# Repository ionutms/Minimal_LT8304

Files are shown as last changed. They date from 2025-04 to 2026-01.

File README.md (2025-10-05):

# Minimal_LT8304

## Overview

This repository contains a minimal KiCad design project for the Analog Devices LT8304, a monolithic micropower isolated flyback converter. The project includes schematic designs and PCB layout files for implementing this versatile isolated power supply IC.

## Disclaimer

> [!NOTE]
> This project is provided "as is" and without any warranty, express or implied. For more details, please see the [LICENSE](LICENSE) file.

## About the LT8304

The LT8304 from Analog Devices is a monolithic micropower isolated flyback converter. It samples the isolated output voltage directly from the primary-side flyback waveform, eliminating the need for a third winding or an opto-isolator for regulation.

Key features include:

- **Input Voltage Range:** 3V to 100V.
- **Power Switch:** An internal 2A, 150V DMOS power switch is integrated.
- **Quiescent Current:** It has a low quiescent current of 116μA in sleep mode and 390μA in active mode.
- **Operation Modes:** It utilizes quasi-resonant boundary mode operation at heavy loads and low ripple Burst Mode® operation at light loads.
- **Package:** It is available in a thermally enhanced 8-lead SO package.
- **Power Delivery:** Can deliver up to 24W of isolated output power.
- **Output Voltage Setting:** The output voltage is set using two external resistors, with an option for a third resistor for temperature compensation.
- **Communication:** Uses a Serial Peripheral Interface (SPI) for configuration and data transfer.
- **Operating Temperature Range:** -40°C to +125°C.

## Project Structure

```
minimal_lt8304/
├── minimal_lt8304.kicad_sch       # Main schematic file
├── minimal_lt8304.kicad_pcb       # PCB layout file
├── minimal_lt8304.kicad_pro       # Project configuration file
├── fp-lib-table                     # Footprint library table
├── sym-lib-table                    # Symbol library table
├── project_jobs_set.kicad_jobset    # Project job settings
├── ibom.config.ini                  # Interactive BOM configuration
├── docs/                            # Documentation files
│   ├── pictures/                    # Images and photos
│   ├── schematics/                  # Schematic PDF exports
│   └── 3d_models/                   # 3D model files
└── KiCAD_Symbols_Generator/         # Submodule for symbol generation from CSV data
```

## Project Features

This design provides a minimal implementation of the LT8304 with the following features:

- **Power Supply:**
  - Wide input voltage range from 3V to 100V.
- **Channel Configuration:**
  - Isolated flyback converter configuration.
- **Bill of Materials (BOM):**
  - Interactive HTML BOM (`ibom.html`) for easy component identification and sourcing.
- **Libraries:**
  - Comprehensive symbol and footprint libraries integrated as a submodule.
- **3D Model:**
  - Includes a 3D model of the board for better visualization.

## Getting Started

### Prerequisites

- [KiCad EDA](https://www.kicad.org/) version 9.0 or later installed on your system
- Git (for cloning the repository and submodule management)

### Opening the Project

1. **Clone the repository** (including submodules):
   ```bash
   git clone --recursive https://github.com/ionutms/Minimal_LT8304.git
   ```
   
   If you've already cloned the repository without submodules, initialize them with:
   ```bash
   git submodule init
   git submodule update
   ```

2. **Open the project in KiCad**:
   - Launch KiCad
   - Click "Open Existing Project"
   - Navigate to the cloned repository folder
   - Select the `minimal_lt8304.kicad_pro` file

3. **Explore the design**:
   - Open the schematic editor to view the circuit design
   - Open the PCB editor to view the board layout
   - Review the symbol and footprint libraries used in the design

### Project Files

- **Main schematic**: `minimal_lt8304.kicad_sch` - Contains the primary circuit design with the LT8304 and support components
- **PCB layout**: `minimal_lt8304.kicad_pcb` - Physical board design file with proper component placement
- **Project configuration**: `minimal_lt8304.kicad_pro` - KiCad project settings

## Dependencies

This project has the following dependencies:

### 1. KiCAD Symbols Generator

This repository uses [KiCAD_Symbols_Generator](https://github.com/ionutms/KiCAD_Symbols_Generator) as a submodule for custom symbol generation.

To initialize the submodule after cloning this repository:

```bash
git submodule update --init --recursive
```

### 2. 3D Models

This project requires the [3D_Models_Vault](https://github.com/ionutms/3D_Models_Vault) repository for 3D models.

#### Setup for KiCAD 9:

1. Clone the 3D models repository:
   ```bash
   git clone https://github.com/ionutms/3D_Models_Vault.git
   ```

2. In KiCAD 9, add an environment variable:
   - Variable name: `KICAD9_3D_MODELS_VAULT`
   - Variable value: Full path to where you cloned the 3D_Models_Vault repository

## Usage

After setting up the dependencies, open the project in KiCad 9 to access all features including the 3D models.

## Symbol Generator Submodule

This project includes the KiCAD_Symbols_Generator as a submodule, which provides tools for generating KiCad symbols from CSV data files. For more information on using this tool, see the [KiCAD_Symbols_Generator documentation](minimal_lt8304/KiCAD_Symbols_Generator/README.md).

## Documentation

The `docs` folder contains:
- Schematic PDF exports
- Images and photos of the design
- 3D model files (GLB and WRL formats)

## Visuals

The following images showcase the PCB design from different perspectives:

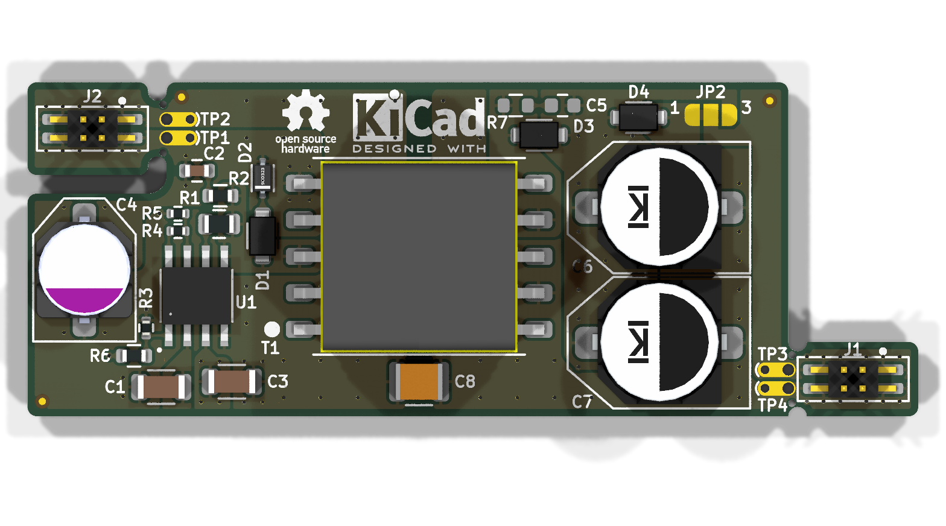
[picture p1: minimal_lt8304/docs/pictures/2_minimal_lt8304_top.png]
Top View

*Top View of the PCB*

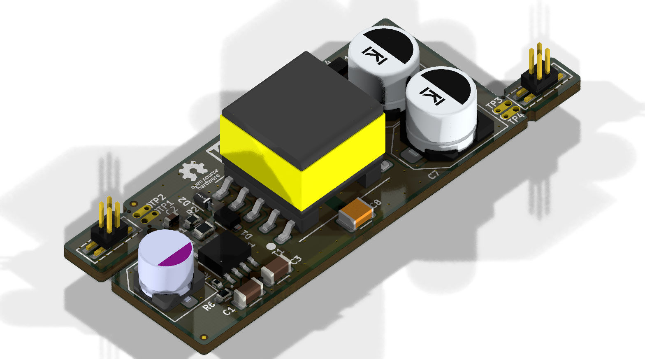
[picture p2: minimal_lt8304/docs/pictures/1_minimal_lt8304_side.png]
Side View

*Side View of the PCB*

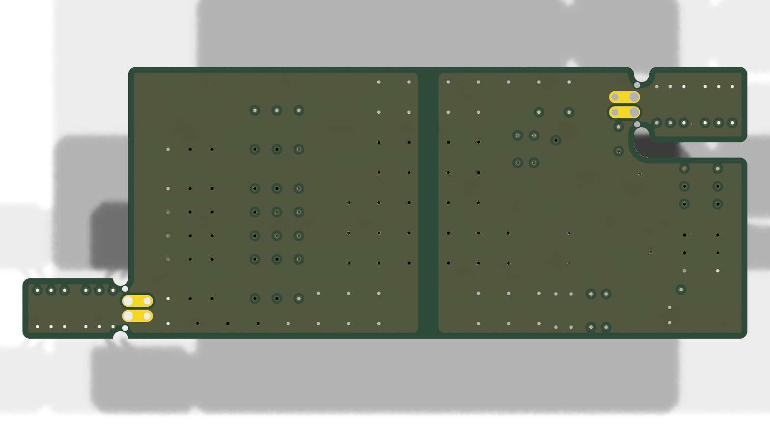
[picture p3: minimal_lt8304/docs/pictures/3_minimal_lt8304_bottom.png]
Bottom View

*Bottom View of the PCB*

## License

This project is licensed under the MIT License - see the [LICENSE](LICENSE) file for details.

## References

- [LT8304 Datasheet](https://www.analog.com/media/en/technical-documentation/data-sheets/lt8304-8304-1.pdf)
- [KiCad EDA](https://www.kicad.org/)

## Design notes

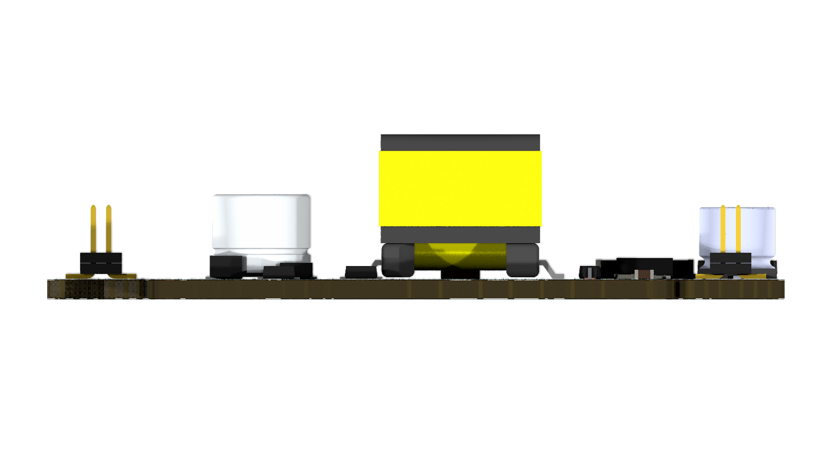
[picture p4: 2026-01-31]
minimal_lt8304/docs/pictures/7_minimal_lt8304_back.png

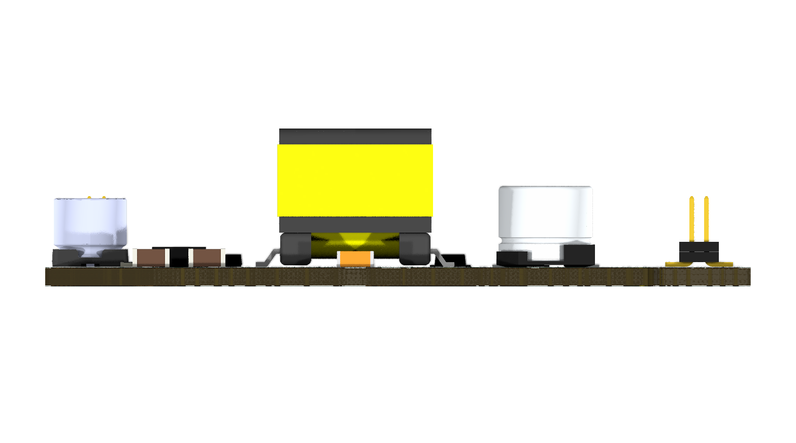
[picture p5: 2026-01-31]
minimal_lt8304/docs/pictures/6_minimal_lt8304_front.png

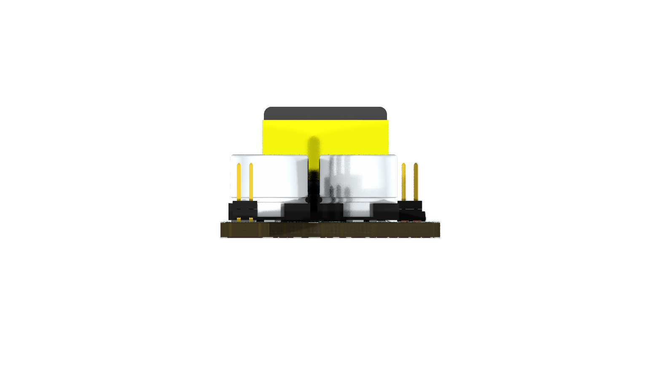
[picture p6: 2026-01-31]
minimal_lt8304/docs/pictures/5_minimal_lt8304_right.png

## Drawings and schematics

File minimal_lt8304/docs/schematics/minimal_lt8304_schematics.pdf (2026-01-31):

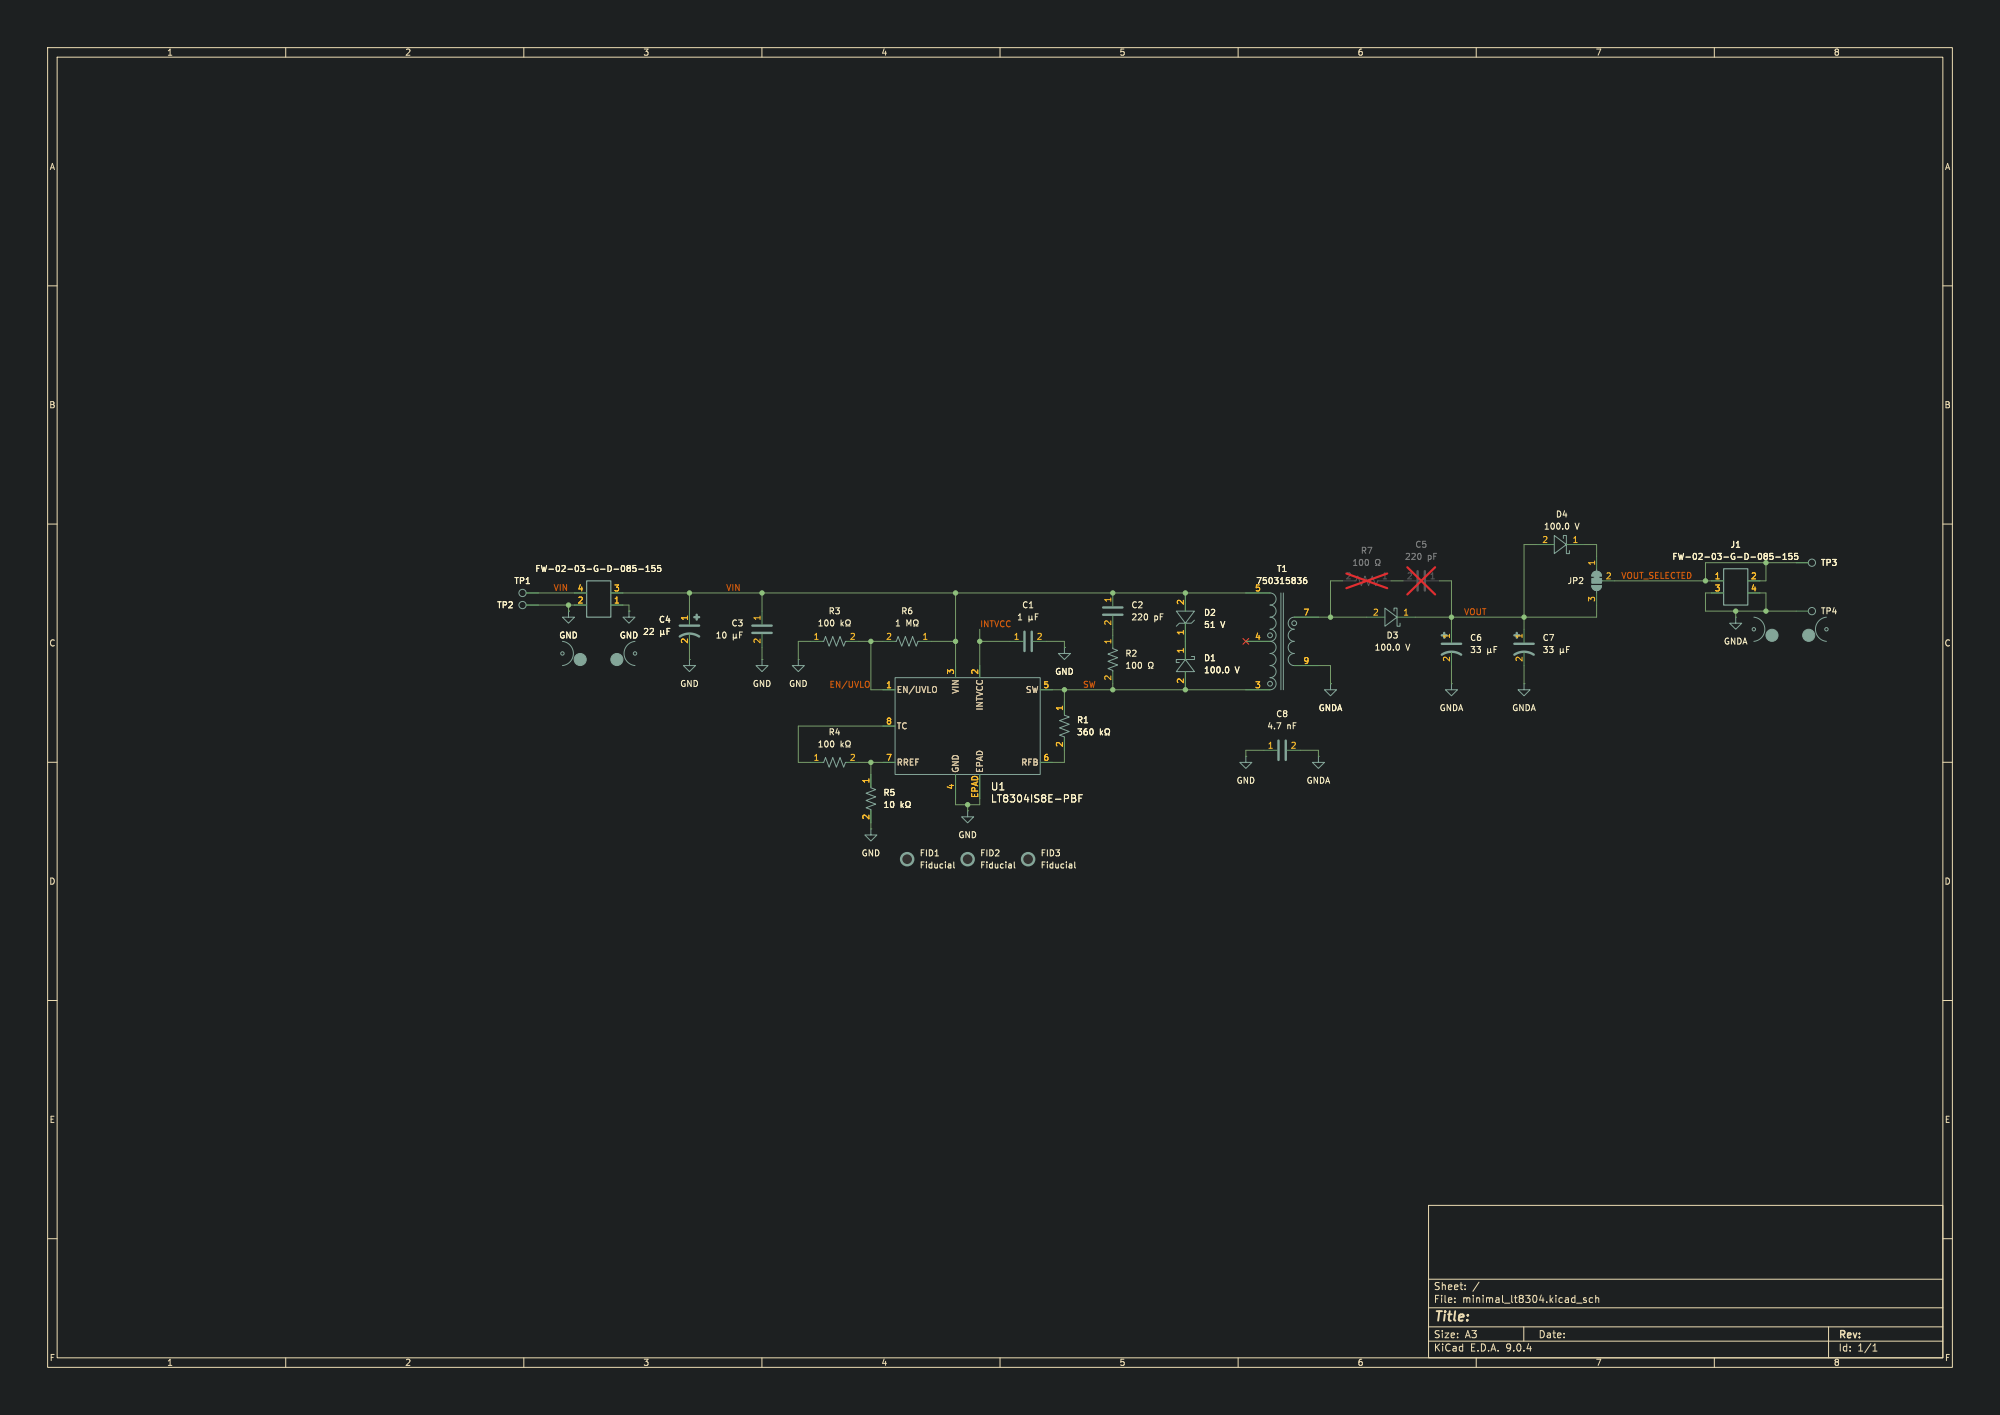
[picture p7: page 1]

33 þÿµF VOUT EN/UVLO

Id: 1/1 Title: File: minimal_lt8304.kicad_sch Sheet: /

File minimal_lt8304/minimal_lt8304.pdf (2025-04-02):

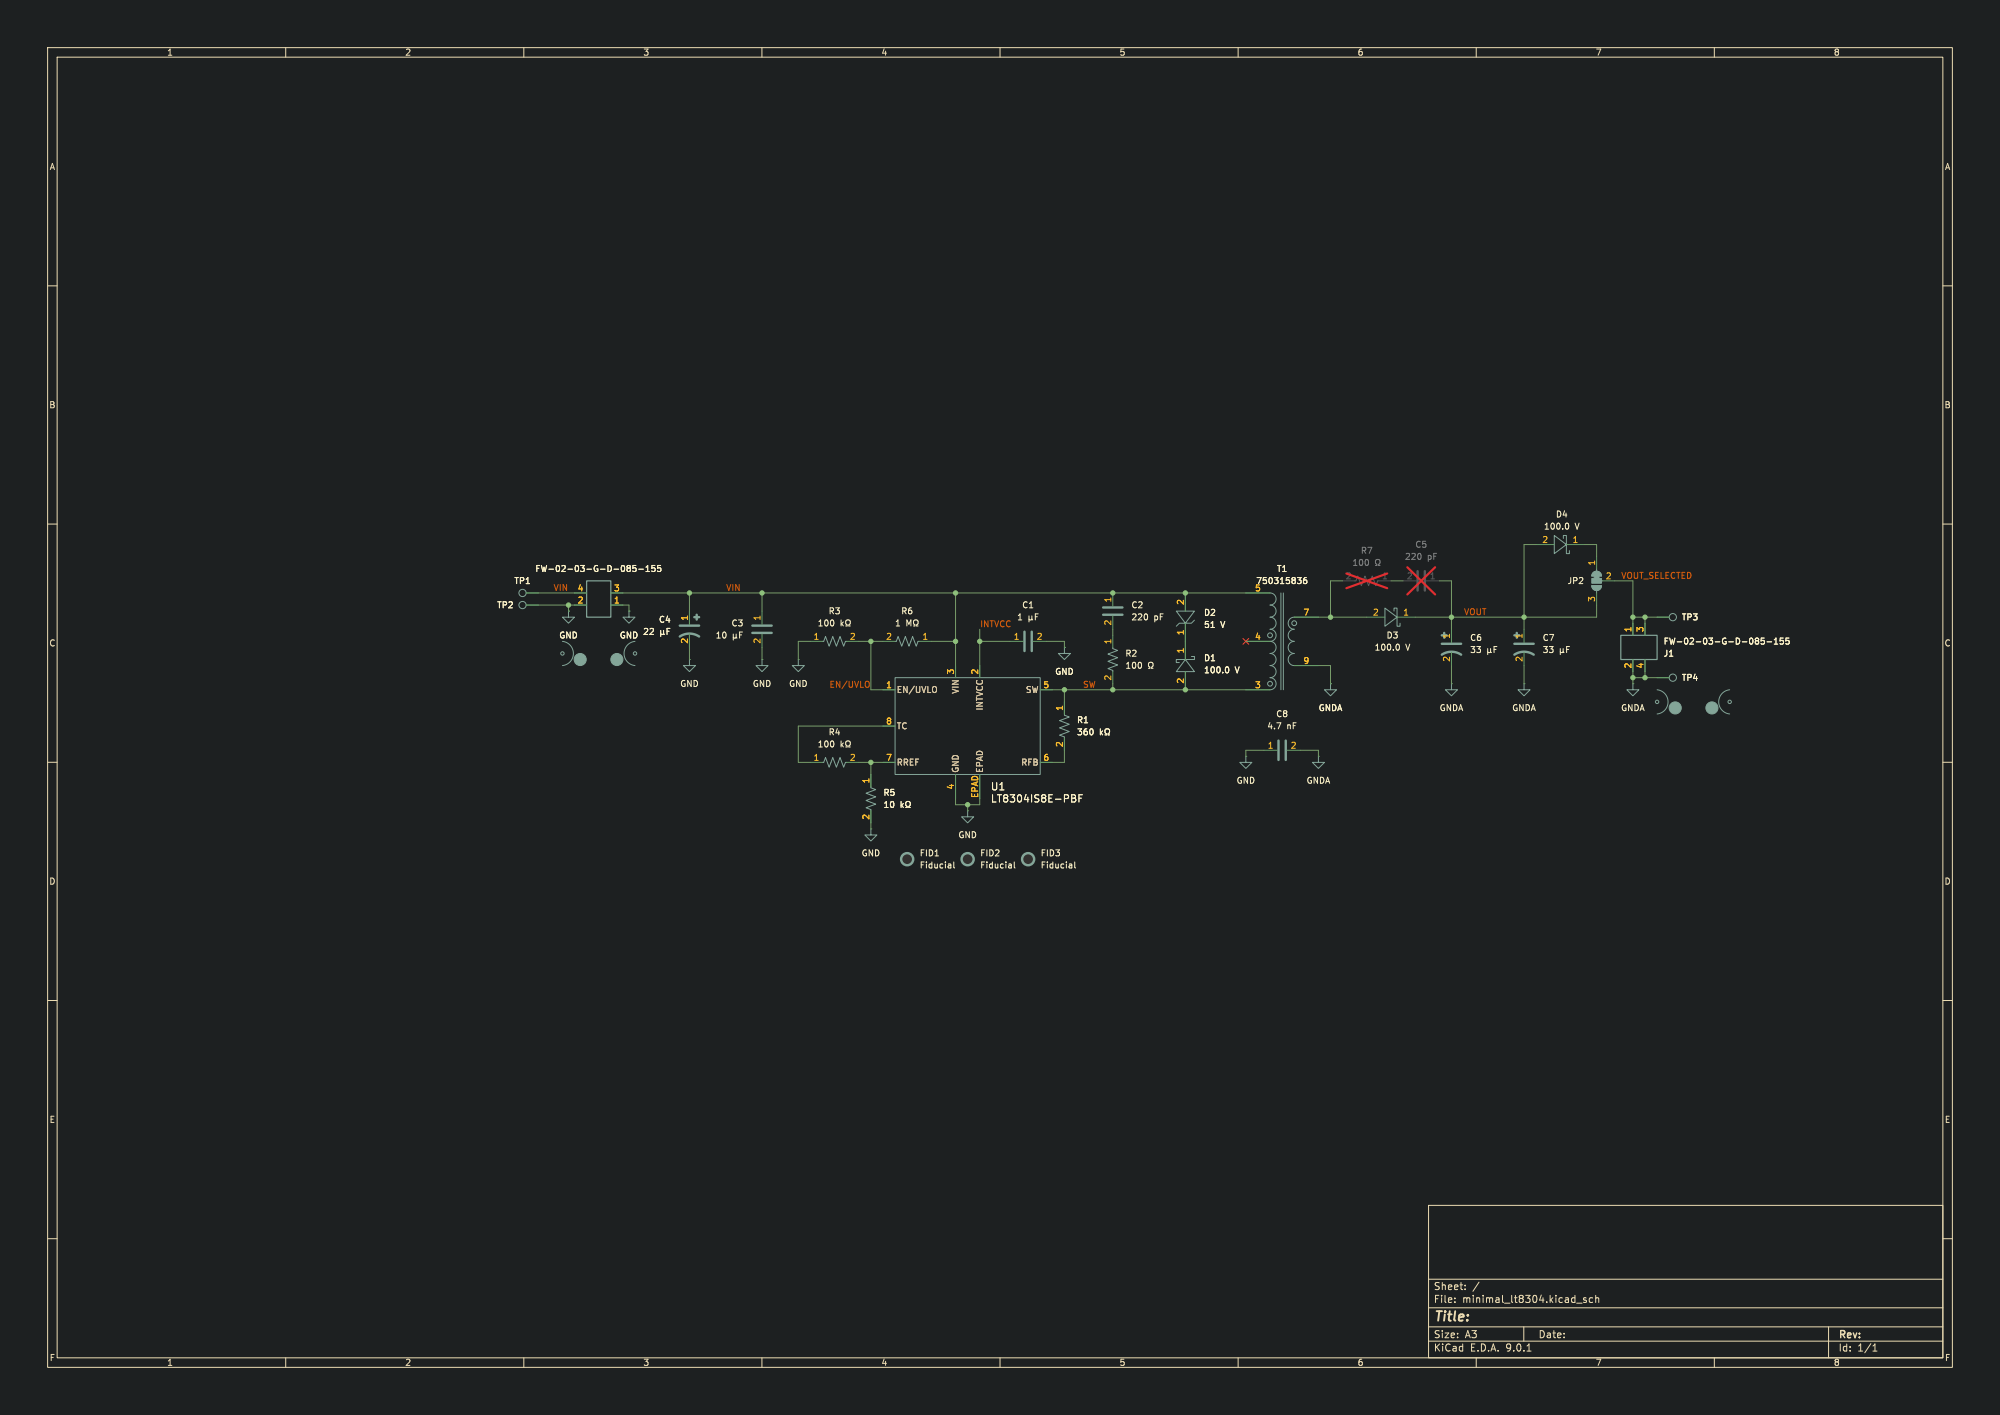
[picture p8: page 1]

Id: 1/1 Title: File: minimal_lt8304.kicad_sch Sheet: /

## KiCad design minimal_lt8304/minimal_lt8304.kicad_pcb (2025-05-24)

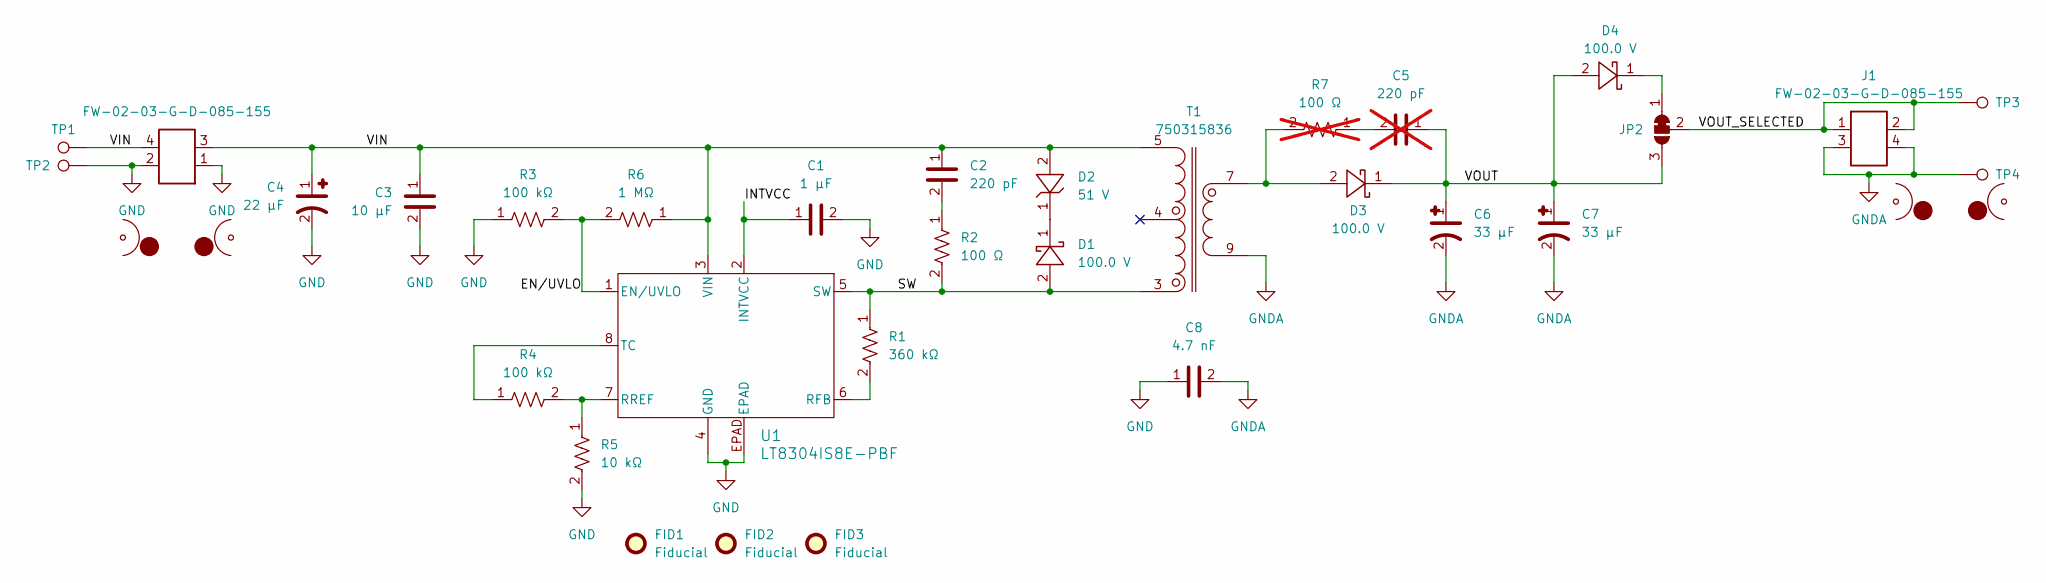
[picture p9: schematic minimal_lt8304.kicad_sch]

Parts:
C1: 1 µF; C_1206_3216Metric; Tolerance 10%; Voltage Rating 25V; MPN C1206R105K3RAC7800
C2: 220 pF; C_0603_1608Metric; Tolerance 5%; Voltage Rating 50V; MPN CC0603JRNPO9BN221
C3: 10 µF; C_1206_3216Metric; Tolerance 10%; Voltage Rating 50V; MPN CL31B106KBHNNN#
C4: 22 µF; C_023x0248_5_9x6_3Metric; Tolerance 20%; Voltage Rating 50V; MPN 50SVPK22M22
C5: 220 pF; C_0603_1608Metric; Tolerance 5%; Voltage Rating 50V; MPN CC0603JRNPO9BN221; not fitted
C6, C7: 33 µF; C_034x0263_8_0x6_7Metric; Tolerance 20%; Voltage Rating 50V; MPN A768KE336M1HLAE042336
C8: 4.7 nF; C_1210_140_3225Metric; Tolerance 10%; Voltage Rating 1.5kV; MPN C1210C472KFRACAUTO
D1, D3, D4: 100.0 V; SOD123W; MPN PMEG10020AELR
D2: 51 V; SOD323; MPN BZX384-B51
FID1, FID2, FID3: Fiducial; Fiducial_0.5mm_Mask1mm
J1, J2: FW-02-03-G-D-085-155; Current Rating (A) 5.2; Voltage Rating (V) 300; MPN FW-02-03-G-D-085-155
JP2: SolderJumper_3_Open; SolderJumper-3_P1.3mm_Bridged_1_2_RoundedPad1.0x1.5mm_Numbe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
MB1, MB2: mouse-bite-midle-50mil-200mil
R1: 360 kΩ; R_0805_2012Metric; Tolerance 1%; Voltage Rating 150V; MPN RC0805FR-07360KL
R2: 100 Ω; R_0603_1608Metric; Tolerance 1%; Voltage Rating 75V; MPN CRCW0603100RFKEAHP
R3, R4: 100 kΩ; R_0402_1005Metric; Tolerance 5%; Voltage Rating 50V; MPN ERJ-2GEJ104X
R5: 10 kΩ; R_0402_1005Metric; Tolerance 1%; Voltage Rating 50V; MPN ERJ-2RKF1002X
R6: 1 MΩ; R_0603_1608Metric; Tolerance 1%; Voltage Rating 75V; MPN ERJ-3EKF1004V
R7: 100 Ω; R_0603_1608Metric; Tolerance 1%; Voltage Rating 75V; MPN CRCW0603100RFKEAHP; not fitted
T1: 750315836; Tolerance ±10%; MPN 750315836
TP1, TP2, TP3, TP4: TestPoint; TestPoint_THTPad_Castelated
U1: LT8304IS8E-PBF; S_8E_ADI

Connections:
/EN/UVLO: R3.2, R6.2, U1.1 (EN/UVLO)
/INTVCC: C1.1, U1.2 (INTVCC)
/SW: D1.2, R1.1, R2.2, T1.3, U1.5 (SW)
/VIN: C2.1, C3.1, C4.1, D2.2, J2.3, J2.4, R6.1, T1.5, TP1.1, U1.3 (VIN)
/VOUT: C5.1, C6.1, C7.1, D3.1, D4.2, JP2.3 (B)
/VOUT_SELECTED: J1.1, J1.2, JP2.2 (C), TP3.1
GND: C1.2, C3.2, C4.2, C8.1, J2.1, J2.2, R3.1, R5.2, TP2.1, U1.4 (GND), U1.EPAD
GNDA: C6.2, C7.2, C8.2, J1.3, J1.4, T1.9, TP4.1
unnamed: C2.2, R2.1
unnamed: C5.2, R7.1
unnamed: D1.1, D2.1
unnamed: D3.2, R7.2, T1.7
unnamed: D4.1, JP2.1 (A)
unnamed: R1.2, U1.6 (RFB)
unnamed: R4.2, R5.1, U1.7 (RREF)
unnamed: R4.1, U1.8 (TC)

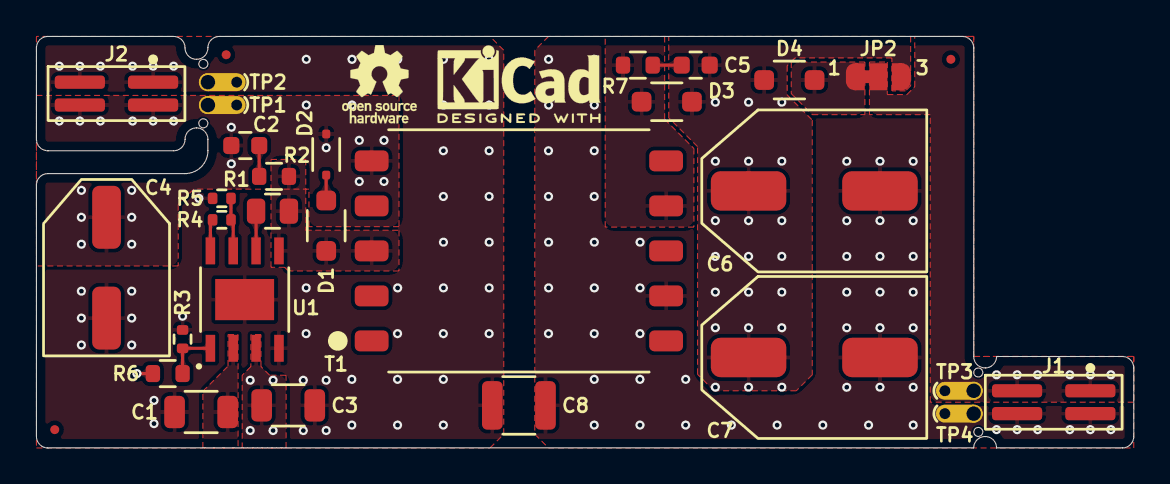
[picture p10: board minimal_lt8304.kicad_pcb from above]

Board: 4 copper layers, 61.0 x 22.9 mm, 33 parts (0 on the bottom side), 16 nets.

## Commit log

2025-03-12 Add initial KiCad project files for minimal_lt8304
    [minimal_lt8304.kicad_pcb, minimal_lt8304.kicad_sch]
2025-03-12 Add submodule for KiCAD Symbol Generator
2025-03-12 Add footprint and symbol library tables for KiCad project
2025-03-12 Update KiCad project files and submodule reference for minimal_lt8304
2025-03-13 Update KiCad project configuration and add ibom configuration file
    [minimal_lt8304.kicad_pcb, minimal_lt8304.kicad_sch]
2025-03-14 Update project
    [minimal_lt8304.kicad_pcb, minimal_lt8304.kicad_sch]
2025-03-14 Update ibom configuration to include additional component blacklist
    [minimal_lt8304.kicad_pcb, minimal_lt8304.kicad_sch]
2025-03-16 Remove submodule reference for KiCAD Symbol Generator
2025-03-16 Add submodule reference for KiCAD Symbols Generator
2025-03-16 Update footprint library URIs to use KiCAD Symbols Generator
    [minimal_lt8304.kicad_pcb]
2025-03-18 Switch to KiCad 9
    [minimal_lt8304.kicad_pcb, minimal_lt8304.kicad_sch]
2025-03-20 Add special_execute command for rendering top view of minimal_lt8304 PCB
2025-03-20 Update subproject reference for KiCAD Symbols Generator in minimal_lt8304
2025-03-20 Update minimal_lt8304 binary files and add top view image for enhanced visualization
    [minimal_lt8304.kicad_pcb]
2025-03-21 Update README.md to include project dependencies and setup instructions for KiCAD and 3D models
2025-03-21 Small project update
    [minimal_lt8304.kicad_pcb, minimal_lt8304.kicad_sch]
2025-04-18 Update default zoom factor in kicad-config.yml to improve visibility
2025-04-18 Update KiCad documentation (schematics and PCB renders)
2025-04-18 Update default zoom factor in kicad-config.yml to enhance visibility
2025-04-25 development backup
    [minimal_lt8304.kicad_pcb, minimal_lt8304.kicad_sch]
2025-04-25 Refactor KiCad configuration and update workflow to utilize new zoom factors and improve output handling
2025-04-25 Remove unused schematic and image files for minimal LT8304
2025-04-25 Update KiCad documentation for minimal_lt8304 (schematics and PCB renders)
2025-04-25 Adjust side view zoom factor and pan settings in KiCad configuration
2025-04-25 Adjust side view pan setting in KiCad configuration
2025-05-07 Update subproject commit for KiCAD Symbols Generator
2025-05-24 Add GitHub Actions workflow to generate KiCad 3D models
2025-05-25 Update trigger branch for KiCad 3D models generation workflow
2025-08-18 Update KiCAD configuration and workflow files
2025-08-22 Update GitHub workflow files for KiCad automation
2025-08-29 Update GitHub workflows for KiCad models and jobs
2025-10-05 chore: update workflows and kicad config from central repository
2025-10-26 Update kicad-config workflow settings
